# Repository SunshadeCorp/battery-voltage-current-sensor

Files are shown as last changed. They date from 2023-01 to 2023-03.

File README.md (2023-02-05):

# battery-voltage-current-sensor
Sensor Board for a voltage and current measurement

D1 Mini ESP8266 Microcontroller

Umax: 750VDC

Imax: +-50A 

Integrated supply voltage generation from the highvoltage source

2x temperature sensors onboard for system monitoring and overload protection

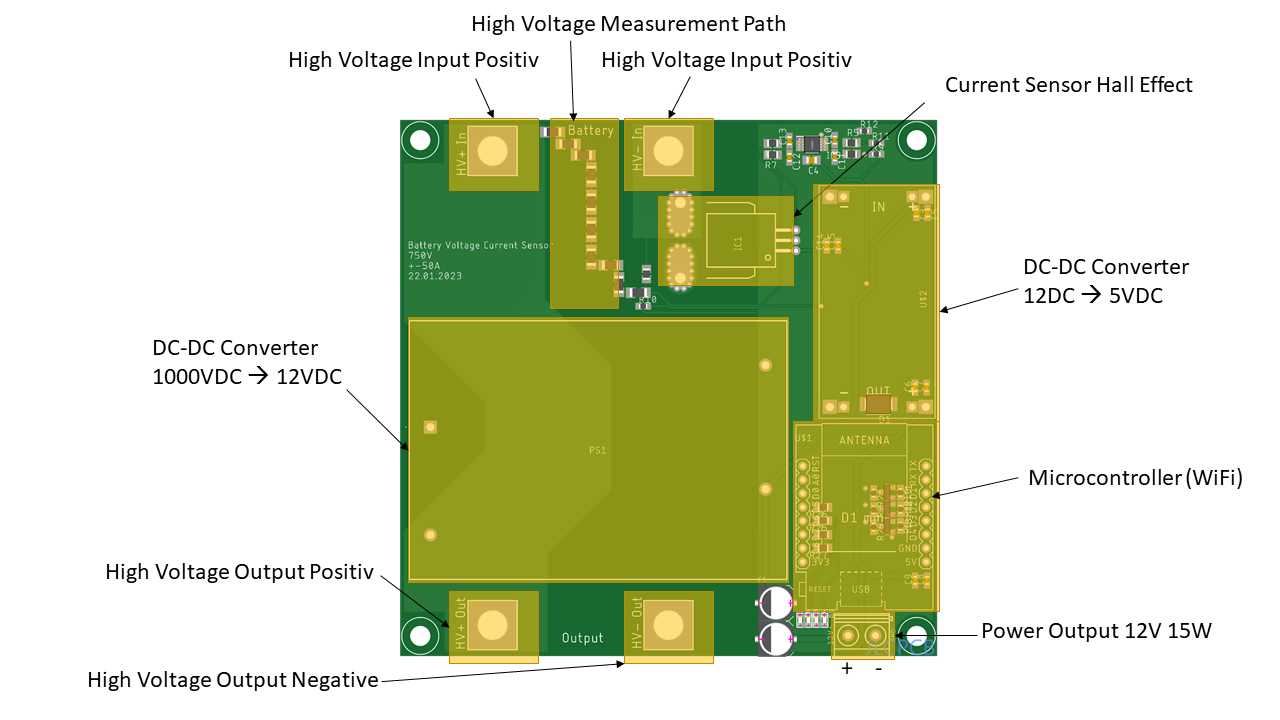
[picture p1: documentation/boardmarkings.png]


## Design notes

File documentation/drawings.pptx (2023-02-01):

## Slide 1

High Voltage Input Positiv

High Voltage Measurement Path

High Voltage Input Positiv

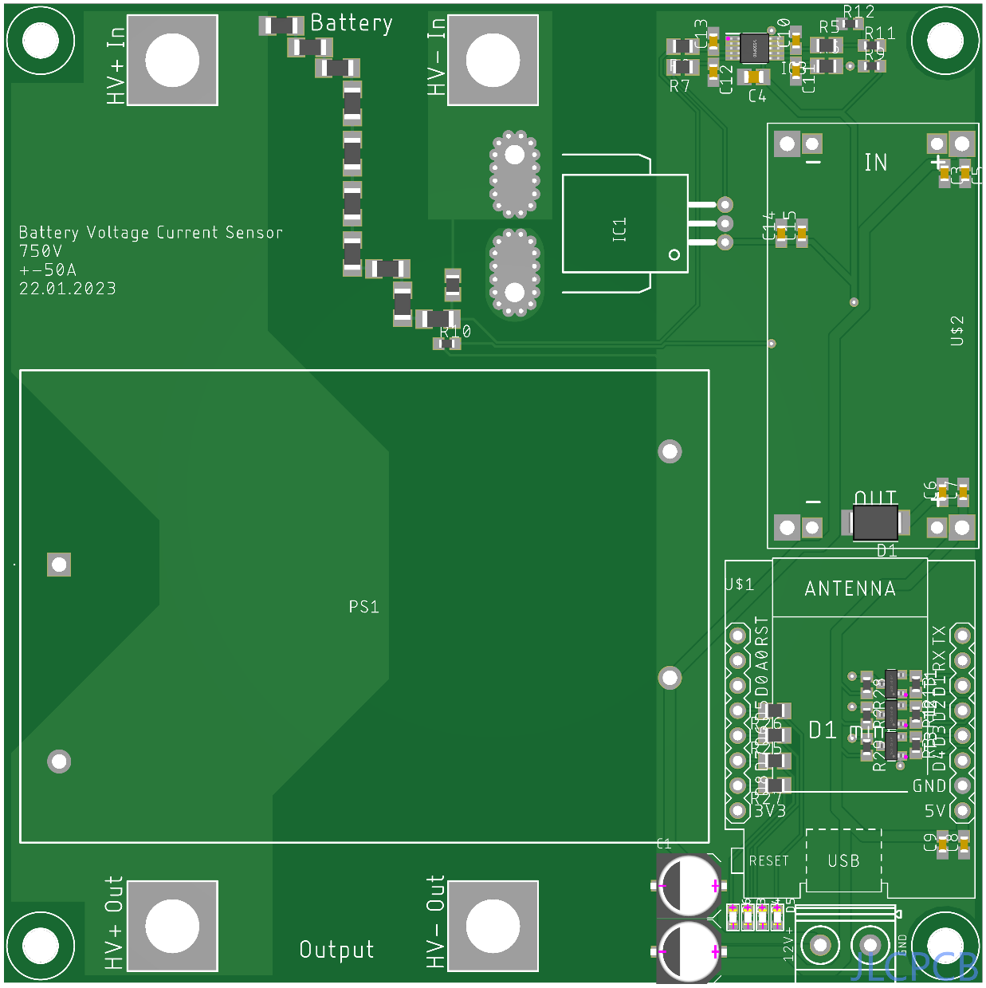
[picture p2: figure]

Current Sensor Hall Effect

DC-DC Converter
12DC → 5VDC

DC-DC Converter
1000VDC → 12VDC

Microcontroller (WiFi)

High Voltage Output Positiv

+ -

Power Output 12V 15W

High Voltage Output Negative

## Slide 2

Battery
600V
30A

+

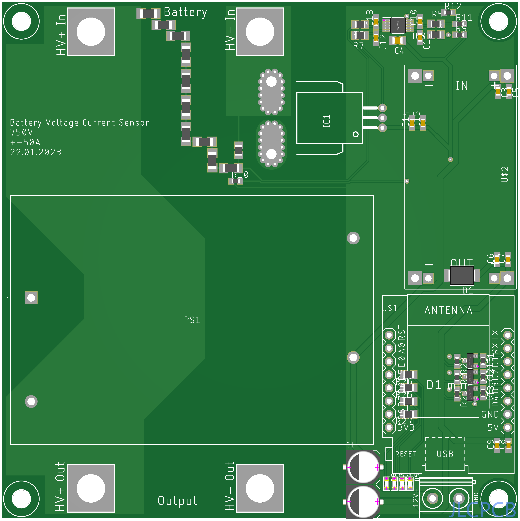
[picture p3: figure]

EasyBMS
Master

+

Inverter

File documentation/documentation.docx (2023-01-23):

Documentation Battery Voltage Current Sensor

This board can be installed in the main power path of a high voltage battery storage. It can measure the voltage and current. The power supply is provided by the high voltage source.

- Umax : 750VDC (isolated up to 1000VDC)
- Imax : +- 50A
- No external power needed
- Absolut safe isolation concept, all data are sent via WiFi
- 100mm x 100mm board size

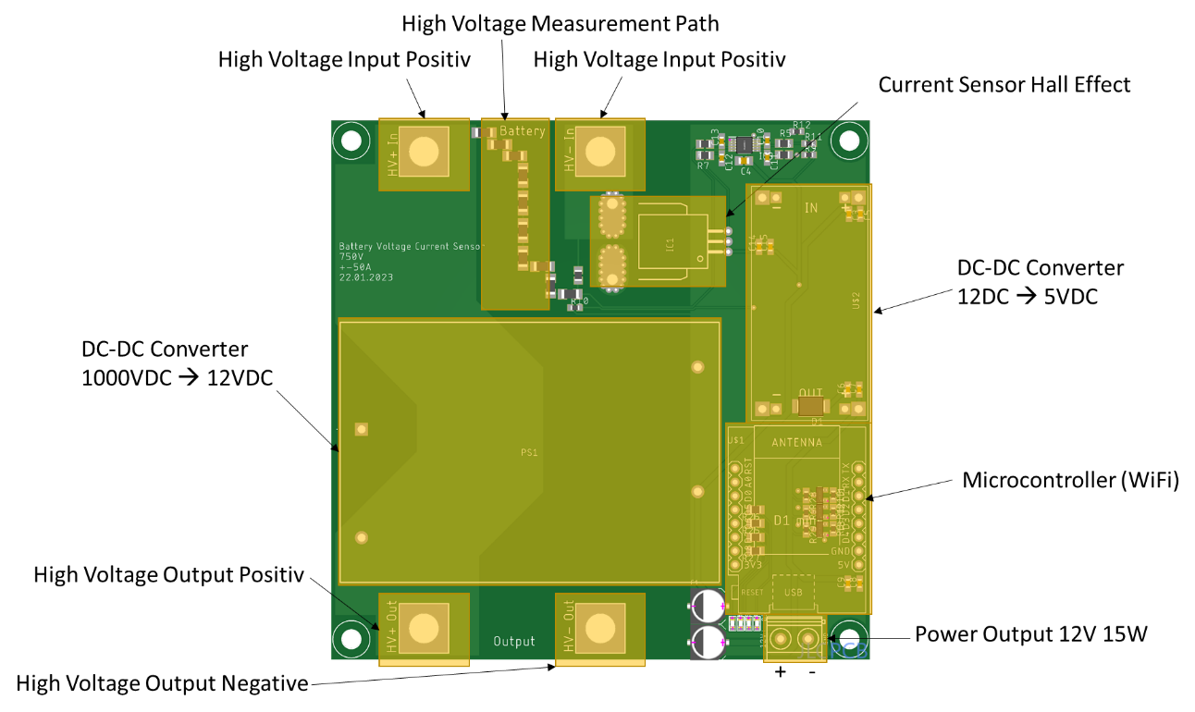
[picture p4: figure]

Basic connection diagram:

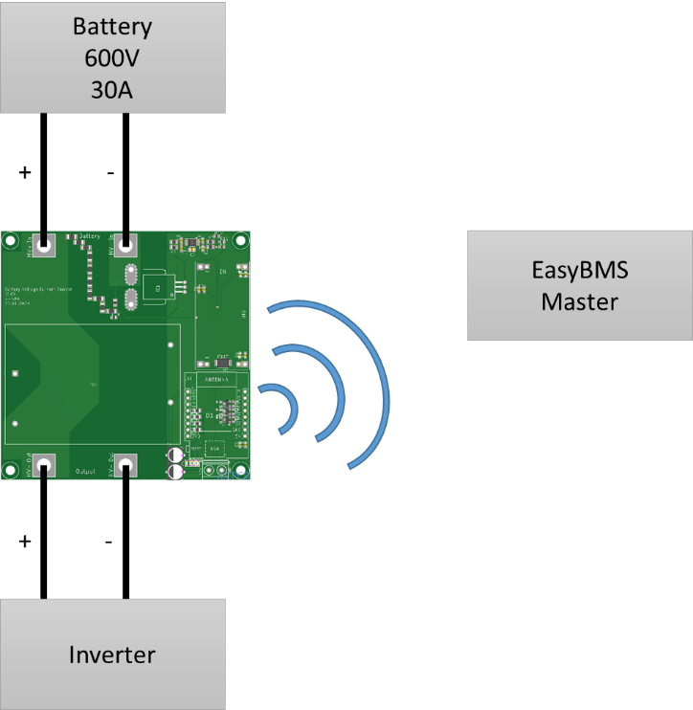
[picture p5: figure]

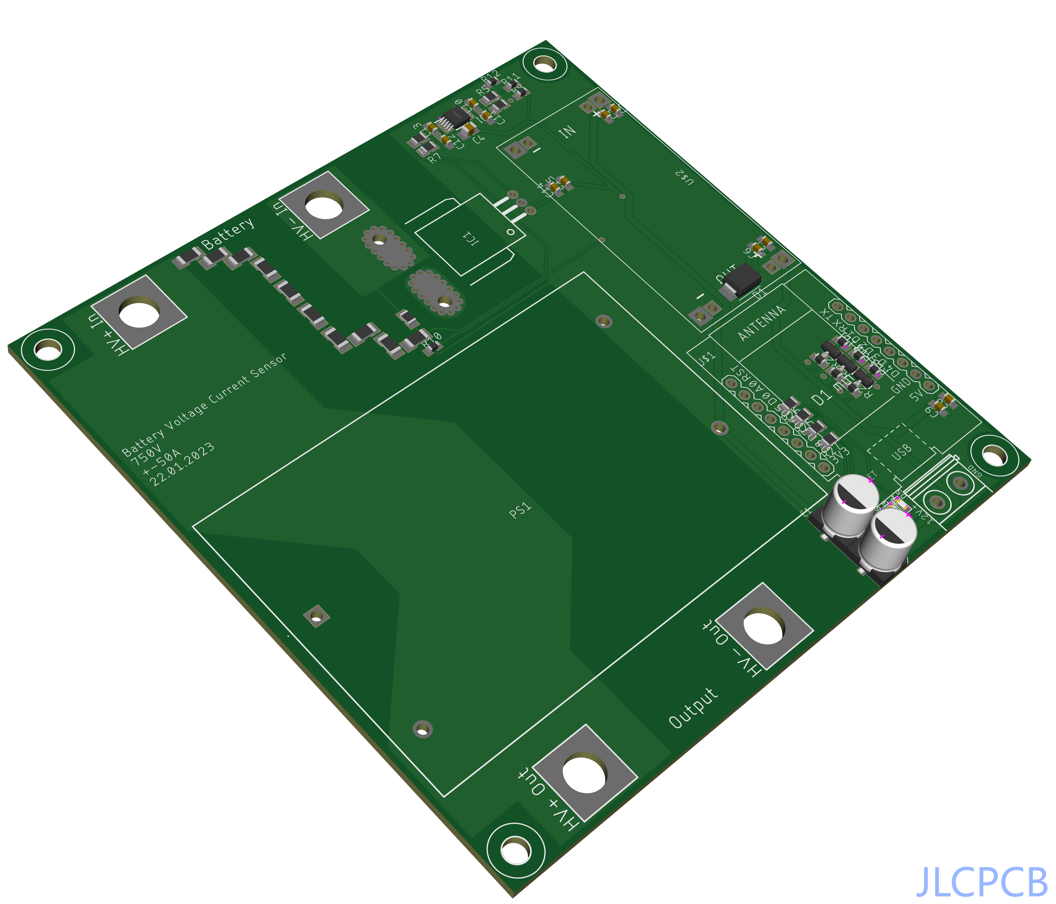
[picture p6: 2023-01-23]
documentation/Board3D.png

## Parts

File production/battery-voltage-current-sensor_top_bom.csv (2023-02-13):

Comment | Designator | Footprint | LCSC Part #
1k | R5 R6 R7 R8 R14 R25 R26 R27 | R0805
10k | R1 R2 R3 R9 R11 R13 R28 R29 | R0603
100nF | C3 | C0603
100nF | C4 | C0805
100nF | C5 C6 C7 C8 C9 C10 C11 C12 C13 C14 C15 | C0603
ADS1115IDGST | IC3 | SOP50P490X110-10N
C8545 | T1 T2 T3 | SOT-23
C13564 | R10 R12 | R0603
C17772 | R24 | R0805
C17900 | R4 R15 R16 R17 R18 R19 R20 R21 R22 R23 | R1206
C78395 | D1 | SMB
C473426 | C1 | UD-6 3X7 7_NICHICON
C473426 | C2 | UD-6 3X7 7_NICHICON
KT-0603R | D3 D4 D5 D6 | LED-0603

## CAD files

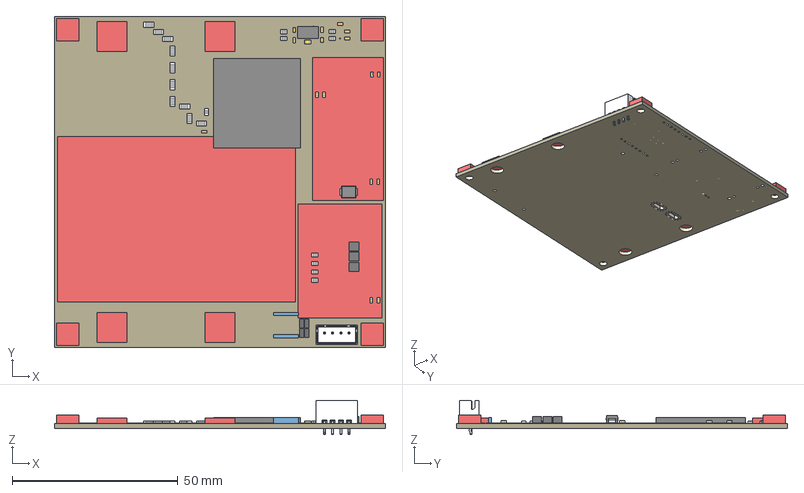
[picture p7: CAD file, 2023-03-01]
documentation/battery-voltage-current-sensor.step
100.0 x 100.0 x 10.4 mm
Board
PV15-27B12R3
MOUNT-PAD-SQUARE5.5 x 4
MOUNT-HOLE3.3 x 4
WEMOS-D1-MINI
ACS758LCB-050B-PFF-T
ADS1115IDGST
C17900 x 10
1k x 9
100nF
DC-DC-STEP-DOWN-LM2596HVS
C473426 x 2
100nF_1 x 12
10k x 10
C78395
KT-0603R x 4
C8545 x 3
B4B-XH-A(LF)(SN)

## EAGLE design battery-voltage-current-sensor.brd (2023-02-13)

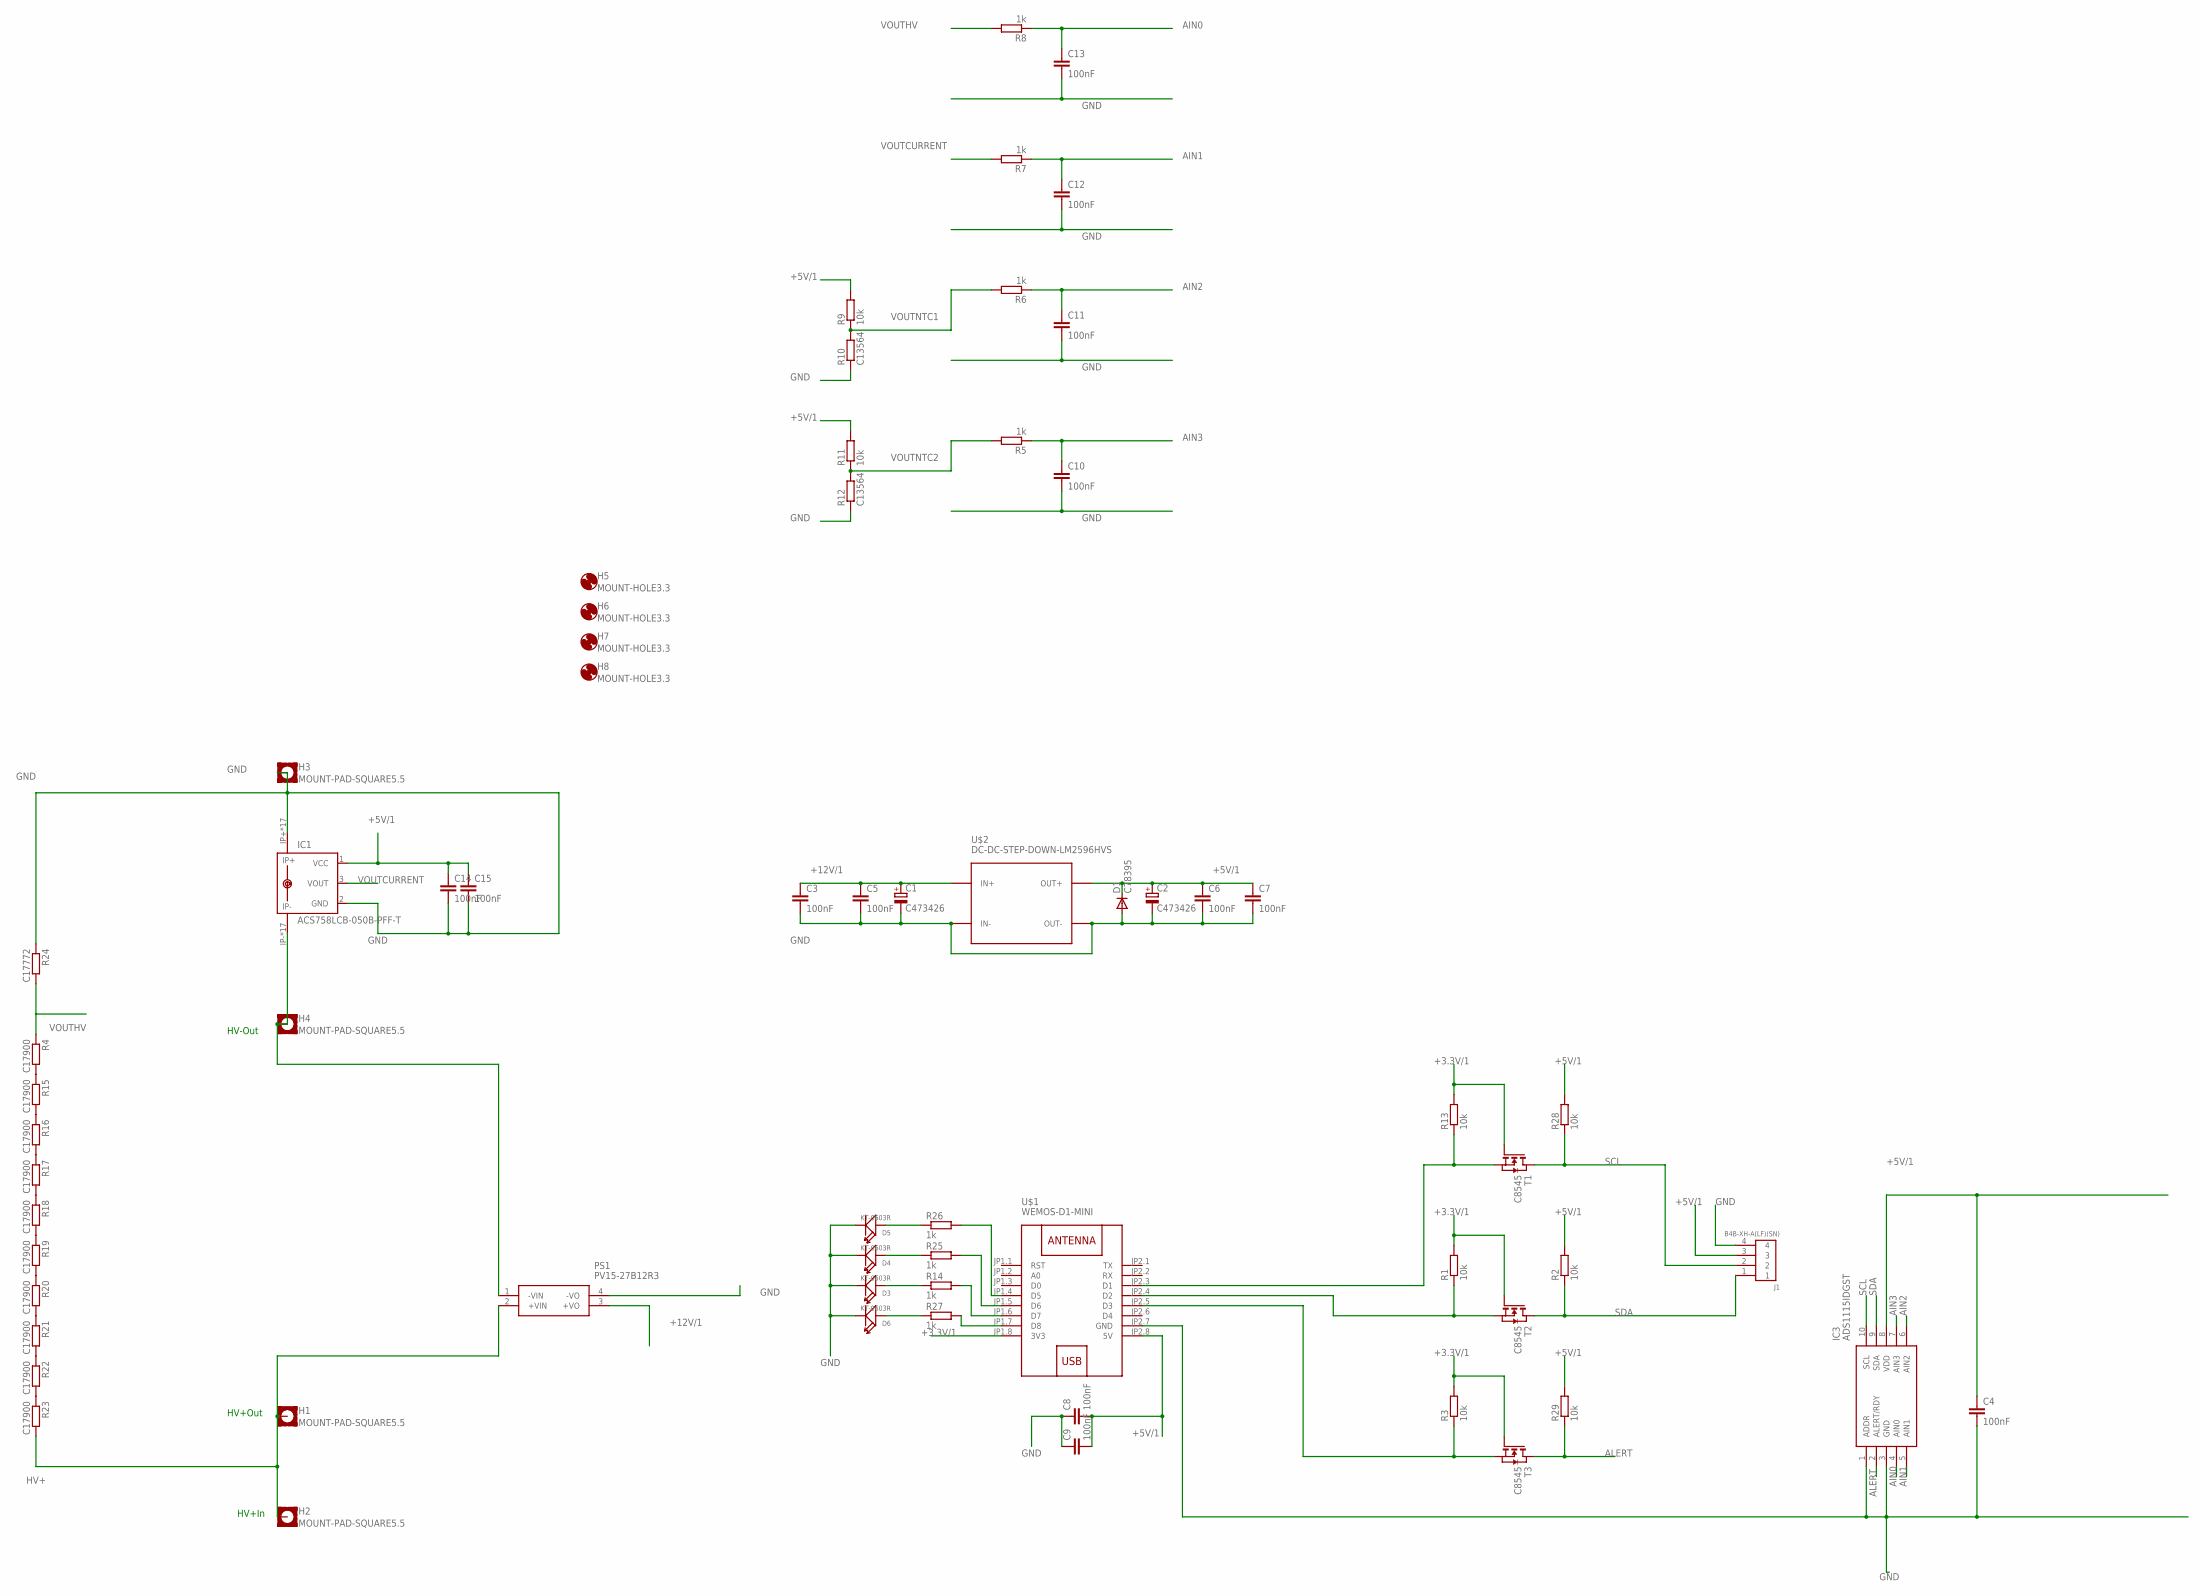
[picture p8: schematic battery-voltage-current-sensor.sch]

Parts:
C1, C2: C473426; UD-6,3X7,7_NICHICON
C3, C5, C6, C7, C8, C9, C10, C11, C12, C13, C14, C15: 100nF; C0603
C4: 100nF; C0805
D1: C78395; SMB
D3, D4, D5, D6: KT-0603R; LED-0603
H1, H2, H3, H4: MOUNT-PAD-SQUARE5.5; 5,5-PAD-SQUARE
H5, H6, H7, H8: MOUNT-HOLE3.3; 3,3
IC1: ACS758LCB-050B-PFF-T; CB-PFF
IC3: ADS1115IDGST; SOP50P490X110-10N
J1: B4B-XH-A(LF)(SN)
PS1: PV15-27B12R3; PV1527B12R3
R1, R2, R3, R9, R11, R13, R28, R29: 10k; R0603
R4, R15, R16, R17, R18, R19, R20, R21, R22, R23: C17900; R1206
R5, R6, R7, R8, R14, R25, R26, R27: 1k; R0805
R10, R12: C13564; R0603
R24: C17772; R0805
T1, T2, T3: C8545; SOT-23
U$1: WEMOS-D1-MINI
U$2: DC-DC-STEP-DOWN-LM2596HVS

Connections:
+3.3V/1: R1.2, R3.2, R13.2, T1.3 (G), T2.3 (G), T3.3 (G), U$1.JP1.8 (3V3)
+5V/1: C2.+, C4.1, C6.1, C7.1, C8.2, C9.2, C14.1, C15.1, D1.C, IC1.1 (VCC), IC3.8 (VDD), J1.3, R2.2, R9.2, R11.2, R28.2, R29.2, U$1.JP2.8 (5V), U$2.OUT+
+12V/1: C1.+, C3.1, C5.1, PS1.3 (+VO), U$2.IN+
AIN0: C13.1, IC3.4 (AIN0), R8.1
AIN1: C12.1, IC3.5 (AIN1), R7.1
AIN2: C11.1, IC3.6 (AIN2), R6.1
AIN3: C10.1, IC3.7 (AIN3), R5.1
ALERT: IC3.2 (ALERT/RDY), R29.1, T3.1 (D)
GND: C1.-, C2.-, C3.2, C4.2, C5.2, C6.2, C7.2, C8.1, C9.1, C10.2, C11.2, C12.2, C13.2, C14.2, C15.2, D1.A, D3.-, D4.-, D5.-, D6.-, H3.B5,5, IC1.2 (GND), IC1.IP+, IC1.IP+@2 (IP+), IC1.IP+@3 (IP+), IC1.IP+@4 (IP+), IC1.IP+@5 (IP+), IC1.IP+@6 (IP+), IC1.IP+@7 (IP+), IC1.IP+@8 (IP+), IC1.IP+@9 (IP+), IC1.IP+@10 (IP+), IC1.IP+@11 (IP+), IC1.IP+@12 (IP+), IC1.IP+@13 (IP+), IC1.IP+@14 (IP+), IC1.IP+@15 (IP+), IC1.IP+@16 (IP+), IC1.IP+@17 (IP+), IC3.1 (ADDR), IC3.3 (GND), J1.4, PS1.4 (-VO), R10.1, R12.1, R24.1, U$1.JP2.7 (GND), U$2.IN-, U$2.OUT-
HV+: H1.B5,5, H2.B5,5, PS1.2 (+VIN), R23.2
HV-: H4.B5,5, IC1.IP-, IC1.IP-@2 (IP-), IC1.IP-@3 (IP-), IC1.IP-@4 (IP-), IC1.IP-@5 (IP-), IC1.IP-@6 (IP-), IC1.IP-@7 (IP-), IC1.IP-@8 (IP-), IC1.IP-@9 (IP-), IC1.IP-@10 (IP-), IC1.IP-@11 (IP-), IC1.IP-@12 (IP-), IC1.IP-@13 (IP-), IC1.IP-@14 (IP-), IC1.IP-@15 (IP-), IC1.IP-@16 (IP-), IC1.IP-@17 (IP-), PS1.1 (-VIN)
unnamed: R1.1, T2.2 (S), U$1.JP2.4 (D2)
unnamed: R13.1, T1.2 (S), U$1.JP2.3 (D1)
unnamed: D3.+, R14.1
unnamed: R3.1, T3.2 (S), U$1.JP2.5 (D3)
unnamed: D4.+, R25.1
unnamed: D5.+, R26.1
unnamed: R4.2, R15.1
unnamed: R15.2, R16.1
unnamed: R16.2, R17.1
unnamed: R17.2, R18.1
unnamed: R18.2, R19.1
unnamed: R19.2, R20.1
unnamed: R20.2, R21.1
unnamed: R21.2, R22.1
unnamed: R22.2, R23.1
unnamed: D6.+, R27.1
unnamed: R27.2, U$1.JP1.7 (D8)
unnamed: R14.2, U$1.JP1.6 (D7)
unnamed: R25.2, U$1.JP1.5 (D6)
unnamed: R26.2, U$1.JP1.4 (D5)
SCL: IC3.10 (SCL), J1.2, R28.1, T1.1 (D)
SDA: IC3.9 (SDA), J1.1, R2.1, T2.1 (D)
VOUTCURRENT: IC1.3 (VOUT), R7.2
VOUTHV: R4.1, R8.2, R24.2
VOUTNTC1: R6.2, R9.1, R10.2
VOUTNTC2: R5.2, R11.1, R12.2

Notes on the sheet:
HV+In
HV+Out
HV-Out

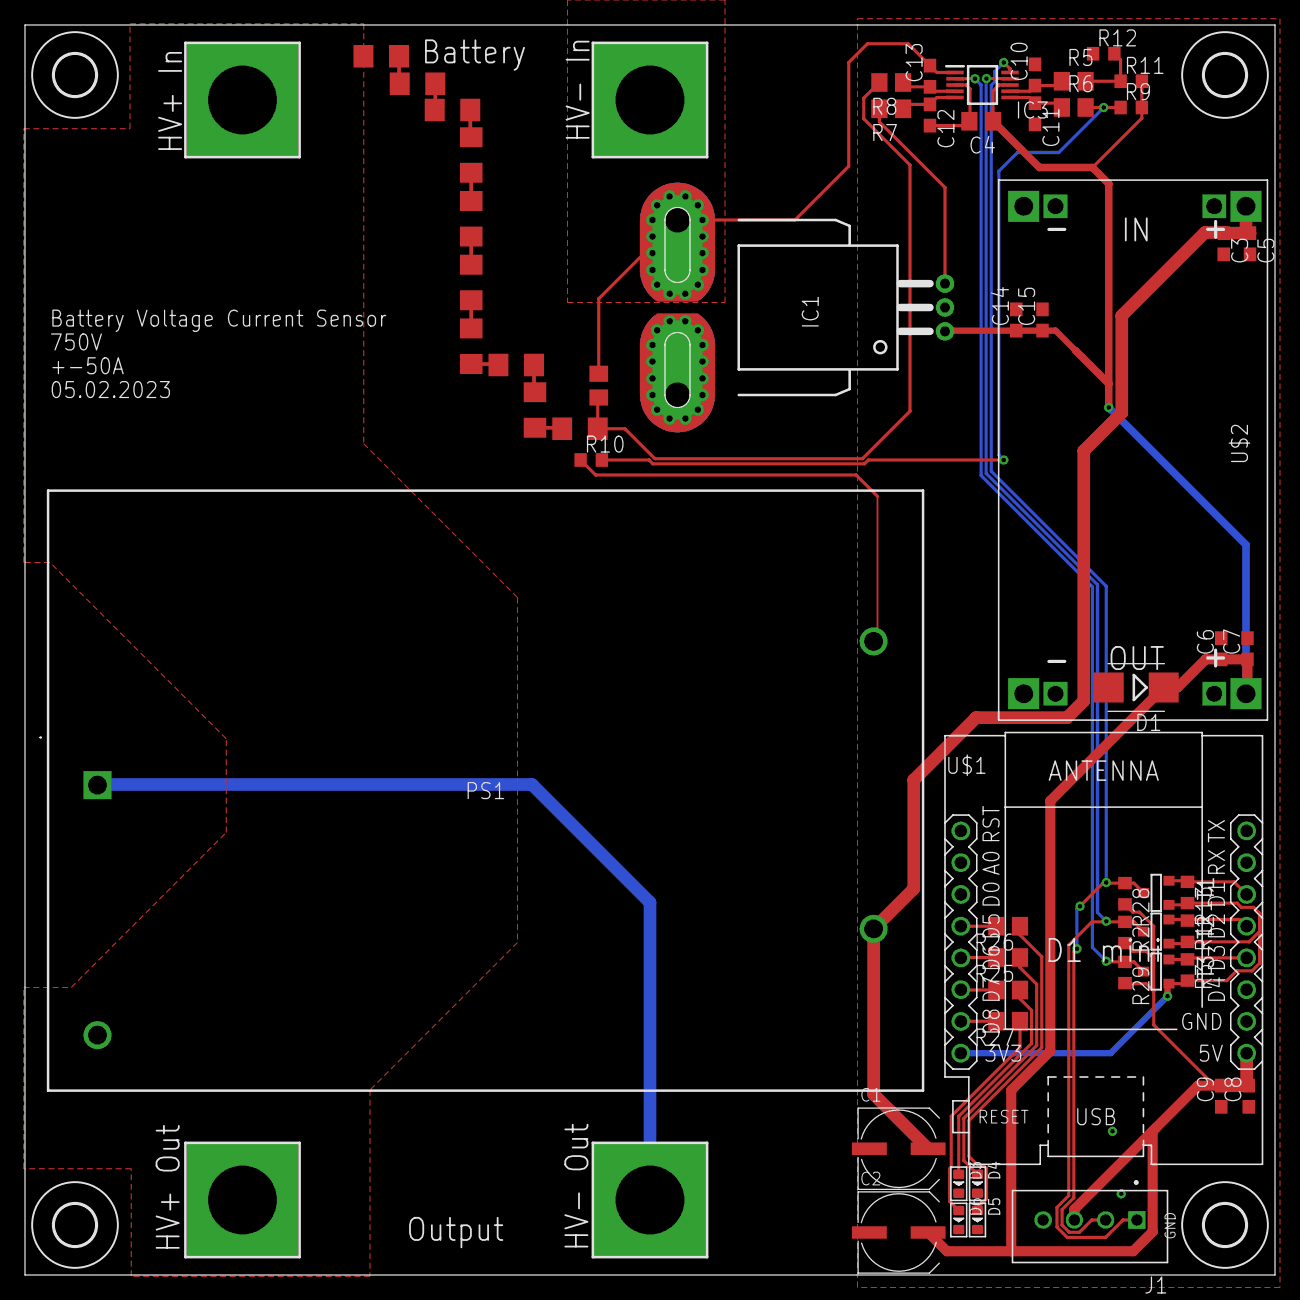
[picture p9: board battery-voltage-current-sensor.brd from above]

Board: 2 copper layers, 100.0 x 100.0 mm, 66 parts (0 on the bottom side), 37 nets.

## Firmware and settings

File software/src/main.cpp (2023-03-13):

#include <Adafruit_ADS1X15.h>
#include <Arduino.h>
#include <ESP8266httpUpdate.h>
#include <ESP8266WiFi.h>
#include <lwip/dns.h>
#include <PubSubClient.h>

#include "config.h"
#include "version.h"

#define intmax 32767.0f

Adafruit_ADS1115 ads;
WiFiClient espClient;
PubSubClient client(mqtt_server, mqtt_port, espClient);

constexpr unsigned long MEASURE_INTERVAL = 500;
constexpr unsigned long BLINK_TIME = 5000;

String hostname;
String sensor_topic("esp-total");

unsigned long last_blink = 0;
unsigned long last_connection = 0;
unsigned long last_measure = 0;

#define MSG_BUFFER_SIZE 50
char msg[MSG_BUFFER_SIZE];
int value = 0;
float current_offset = 0.0f;

float readVoltage();                // Reads a voltage from an Input Pin of the ADC
float readCurrent();                // Reads a current from an Input Pin of the ADC
float readTemperature(int adc_pin); // Reads a temperatuer measured by a NTC from the Input Pin of the ADC

void connectWifi() {
    Serial.println();
    Serial.print("connecting to ");
    Serial.println(ssid);
    ESP8266WiFiClass::persistent(false);
    WiFi.softAPdisconnect(true);
    WiFi.mode(WIFI_STA);
    WiFi.hostname(hostname);
    WiFi.begin(ssid, password);
    while (WiFi.status() != WL_CONNECTED) {
        delay(100);
        Serial.print(".");
    }
    Serial.println("");
    Serial.println("WiFi connected");
    Serial.println("IP address: ");
    Serial.println(WiFi.localIP());

    Serial.print("DNS1: ");
    Serial.println(IPAddress(dns_getserver(0)));
    Serial.print("DNS2: ");
    Serial.println(IPAddress(dns_getserver(1)));
}

void callback(char *topic, byte *payload, unsigned int length) {
    String topic_string = String(topic);
    String payload_string = String();
    payload_string.concat((char *) payload, length);
    if (topic_string == sensor_topic + "/blink") {
        last_blink = millis();
    } else if (topic_string == sensor_topic + "/restart") {
        if (payload_string == "1") {
            EspClass::restart();
        }
    } else if (topic_string == sensor_topic + "/ota") {
        client.publish((sensor_topic + "/ota_start").c_str(),
                       (String("ota started [") + payload_string + "] (" + millis() + ")").c_str());
        client.publish((sensor_topic + "/ota_url").c_str(),
                       (String("https://") + ota_server + payload_string).c_str());
        WiFiClientSecure client_secure;
        client_secure.setTrustAnchors(&cert);
        client_secure.setTimeout(60);
        ESPhttpUpdate.setLedPin(LED_BUILTIN, HIGH);
        switch (ESPhttpUpdate.update(client_secure, String("https://") + ota_server + payload_string)) {
            case HTTP_UPDATE_FAILED: {
                String error_string = String("HTTP_UPDATE_FAILED Error (");
                error_string += ESPhttpUpdate.getLastError();
                error_string += "): ";
                error_string += ESPhttpUpdate.getLastErrorString();
                error_string += "\n";
                Serial.println(error_string);
                client.publish((sensor_topic + "/ota_ret").c_str(), error_string.c_str());
            }
                break;
            case HTTP_UPDATE_NO_UPDATES:
                Serial.println("HTTP_UPDATE_NO_UPDATES");
                client.publish((sensor_topic + "/ota_ret").c_str(), "HTTP_UPDATE_NO_UPDATES");
                break;
            case HTTP_UPDATE_OK:
                Serial.println("HTTP_UPDATE_OK");
                client.publish((sensor_topic + "/ota_ret").c_str(), "HTTP_UPDATE_OK");
                break;
        }
    }
}

void reconnect() {
    // Loop until we're reconnected
    while (!client.connected()) {
        Serial.print("Attempting MQTT connection...");
        // Attempt to connect
        if (client.connect(hostname.c_str(), mqtt_username, mqtt_password, (sensor_topic + "/available").c_str(), 0,
                           true, "offline")) {
            Serial.println("connected");
            // Once connected, publish an announcement...
            client.publish((sensor_topic + "/available").c_str(), "online", true);
            client.publish((sensor_topic + "/version").c_str(), VERSION, true);
            client.publish((sensor_topic + "/build_timestamp").c_str(), BUILD_TIMESTAMP, true);
            // ... and resubscribe
            client.subscribe((sensor_topic + "/blink").c_str());
            client.subscribe((sensor_topic + "/restart").c_str());
            client.subscribe((sensor_topic + "/ota").c_str());
        } else {
            Serial.print("failed, rc=");
            Serial.print(client.state());
            //   DEBUG_PRINTLN(" try again in 5 seconds");
            // Wait 5 seconds before retrying
            // delay(5000);
            if (last_connection != 0 && millis() - last_connection >= 30000) {
                EspClass::restart();
            }
            delay(1000);
        }
    }
}

void setup() {
    Serial.begin(74880);
    pinMode(LED_BUILTIN, OUTPUT);

    Serial.println("Starte Init vom Chip");
    ads.begin(0x48);
    Serial.println("Chip Init done");
    current_offset = readCurrent();

    uint8_t mac[6];
    WiFi.macAddress(mac);
    char mac_string[6 * 2 + 1] = {0};
    snprintf(mac_string, 6 * 2 + 1, "%02x%02x%02x%02x%02x%02x", mac[0], mac[1], mac[2], mac[3], mac[4], mac[5]);
    hostname = String("bvc-sensor-") + mac_string;
    Serial.println(hostname);

    connectWifi();
    randomSeed(micros());
    client.setCallback(callback);
}

void loop() {
    /*
     * MQTT reconnect if needed
     */
    if (!client.connected()) {
        reconnect();
    }
    last_connection = millis();
    client.loop();

    if (millis() - last_measure > MEASURE_INTERVAL) {
        last_measure = millis();

        float current;
        float voltage;
        float temp1;
        float temp2;

        current = readCurrent() - current_offset;
        voltage = readVoltage();
        temp1 = readTemperature(2);
        temp2 = readTemperature(3);

        client.publish((sensor_topic + "/uptime").c_str(), String(millis()).c_str());
        digitalWrite(LED_BUILTIN, LOW);
        snprintf(msg, MSG_BUFFER_SIZE, "%f", voltage);
        client.publish((sensor_topic + "/total_voltage").c_str(), msg);
        snprintf(msg, MSG_BUFFER_SIZE, "%f", current);
        client.publish((sensor_topic + "/total_current").c_str(), msg);
        snprintf(msg, MSG_BUFFER_SIZE, "%f", temp1);
        client.publish((sensor_topic + "/temp1").c_str(), msg);
        snprintf(msg, MSG_BUFFER_SIZE, "%f", temp2);
        client.publish((sensor_topic + "/temp2").c_str(), msg);
        digitalWrite(LED_BUILTIN, HIGH);
    }
    if (millis() - last_blink < BLINK_TIME) {
        if ((millis() - last_blink) % 100 < 50) {
            digitalWrite(LED_BUILTIN, HIGH);
        } else {
            digitalWrite(LED_BUILTIN, LOW);
        }
    }
}

float readCurrent() {
    float adc_value;      // raw value from the ADConverter
    float Uin;            // calculated input voltage at the input of ADC
    float current;        // calculated current
    float offset = 2.545; // Offset of the hall sensor = 2,5V , should configurable over MQTT
    adc_value = ads.readADC_SingleEnded(1); // read analog value from ADC
    delay(10);
    adc_value = adc_value + ads.readADC_SingleEnded(1); // read analog value from ADC
    delay(10);
    adc_value = adc_value + ads.readADC_SingleEnded(1); // read analog value from ADC

    Uin = (((adc_value / 3.0f) / intmax) * 6.144f);
    current = (Uin - offset) / 0.040f; // 40mV/A
    current = -current;
    return (current);
}

float readVoltage() {
    float adc_value;
    float Uin;
    float HV;
    //const float rges = 6800.0 + 10.0 * (100000.0);
    //const float r2 = 6800;
    //manual voltage factor between input voltage and HV voltage
    float factor = 148.52f;


    adc_value = ads.readADC_SingleEnded(0);
    delay(10);
    adc_value = adc_value + ads.readADC_SingleEnded(0);
    delay(10);
    adc_value = adc_value + ads.readADC_SingleEnded(0);

    Uin = (((adc_value / 3.0f) / intmax) * 6.144f);
    //Send raw input voltage
    snprintf(msg, MSG_BUFFER_SIZE, "%f", Uin);
    client.publish("esp-total/Uin", msg);
    HV = Uin * factor;

    return (HV);
}

float readTemperature(int adc_pin) {
    // https://www.mymakerstuff.de/2018/05/18/arduino-tutorial-der-temperatursensor/
    float rt;     //restistance of the thermal resistor
    float rt1 = 10000.0;
    float uges = 5.0;
    float adc_value;


    float b = 3434;
    float TKelvin;
    float kelvintemp = 273.15;
    float Tn = kelvintemp + 25; // Nenntemperatur in Kelvin
    float temperature;
    float Uin;
    adc_value = ads.readADC_SingleEnded(adc_pin); // lese Analogwert aus ADC chip

    Uin = ((adc_value / intmax) * 6.144f);
    rt = ((rt1) * (Uin / uges) / (1 - (Uin / uges)));
    TKelvin = 1 / ((1 / Tn) + ((float) 1 / b) * log((float) rt / rt1)); // ermittle die Temperatur in Kelvin
    temperature = TKelvin - kelvintemp;
    return temperature;
}

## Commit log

2023-01-19 inital commit
    [battery-voltage-current-sensor.brd, battery-voltage-current-sensor.sch]
2023-01-19 DCDC added
    [battery-voltage-current-sensor.brd, battery-voltage-current-sensor.sch]
2023-01-19 basic board and holes added
    [battery-voltage-current-sensor.brd, battery-voltage-current-sensor.sch]
2023-01-19 mounting holes added
    [battery-voltage-current-sensor.brd, battery-voltage-current-sensor.sch]
2023-01-20 first placing check
    [battery-voltage-current-sensor.brd]
2023-01-21 DCDC as a module added
    [battery-voltage-current-sensor.brd, battery-voltage-current-sensor.sch]
2023-01-21 first placing succes
    [battery-voltage-current-sensor.brd, battery-voltage-current-sensor.sch]
2023-01-22 level shifter added
    [battery-voltage-current-sensor.brd, battery-voltage-current-sensor.sch]
2023-01-22 first draft of production data generated
    [battery-voltage-current-sensor.brd, battery-voltage-current-sensor_top_bom.csv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]
2023-01-22 external 12V added
    [battery-voltage-current-sensor.brd, battery-voltage-current-sensor.sch, battery-voltage-current-sensor_top_bom.csv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]
2023-01-22 text added
    [battery-voltage-current-sensor.brd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]
2023-01-22 capacitors moved
    [battery-voltage-current-sensor.brd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]
2023-01-22 marking for 12 connector added
    [battery-voltage-current-sensor.brd]
2023-01-22 3D step added
    [battery-voltage-current-sensor.step]
2023-01-23 ready to manufacture, ordered
    [battery-voltage-current-sensor.brd]
2023-02-04 voltage measurement resistors changed to 100k
    [battery-voltage-current-sensor.brd, battery-voltage-current-sensor.sch]
2023-02-05 1000V DCDC position corrected
    [battery-voltage-current-sensor.brd, battery-voltage-current-sensor.sch]
2023-02-05 current offset at start calibrated
2023-02-05 3d model updated
    [battery-voltage-current-sensor.step]
2023-02-05 Update README.md
    12V source removed, it is dangerous
2023-02-13 error fixed
    [battery-voltage-current-sensor.brd]
2023-02-13 connector swapped against a 4pin for a display
    [battery-voltage-current-sensor.brd, battery-voltage-current-sensor.sch]
2023-02-13 connector rotated, ready to manufacture, ordered
    [battery-voltage-current-sensor.brd, battery-voltage-current-sensor_top_bom.csv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]
2023-02-18 current offset + ota + restart + blink
2023-03-01 updated 3D model
    [battery-voltage-current-sensor.step]
2023-03-13 new voltage factor

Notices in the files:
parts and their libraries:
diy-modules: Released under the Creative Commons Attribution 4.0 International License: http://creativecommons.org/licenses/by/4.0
